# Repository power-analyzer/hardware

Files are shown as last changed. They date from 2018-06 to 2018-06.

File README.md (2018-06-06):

# Hardware

This is the hardware and microcontroller software component of Ryan Rabello and Nathan Zimmerly's senior project.

## Getting Started

The PCB folder is a KiCAD project. Once this is done, 

## Prerequisites

KiCAD and PlatformIO using either Visual Studio Code or Atom.

## Authors

Nathan Zimmerly and Ryan Rabello.

## Acknowledgments

OpenEnergyMonitor

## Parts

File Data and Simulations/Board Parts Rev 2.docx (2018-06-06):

Mux:

1. Link: http://www.ti.com/lit/ds/symlink/cd74hc4067.pdf
  a. Digi-Key Part #: 296-9226-1-ND (https://www.digikey.com/product-detail/en/texas-instruments/CD74HC4067SM96/296-9226-1-ND/376978)
  b. SOIC: https://www.digikey.com/product-detail/en/texas-instruments/CD74HC4067M96/296-29408-2-ND/1507236
  c. Voltage range: 2-6V (only has details for 2, 4, and 6 V).
  d. Multiplexer/Demultiplexer circuit: 16:1
  e. Price: $.38
2. A-D with Mux compare (price)
3. Check A-D for A-D built in voltage. 0-1V
4. USPS

Aux:

1. https://www.amazon.com/gp/huc/view.html?ie=UTF8&newItems=C10de19e9-9e1f-4409-ad12-5c9f6bc3ec91%2C1

Connector:

1. https://www.digikey.com/product-detail/en/phoenix-contact/1792876/277-2519-ND/3439931

Fuse:

1. https://www.digikey.com/product-detail/en/bel-fuse-inc/SMP-1.25/507-1039-2-ND/615115

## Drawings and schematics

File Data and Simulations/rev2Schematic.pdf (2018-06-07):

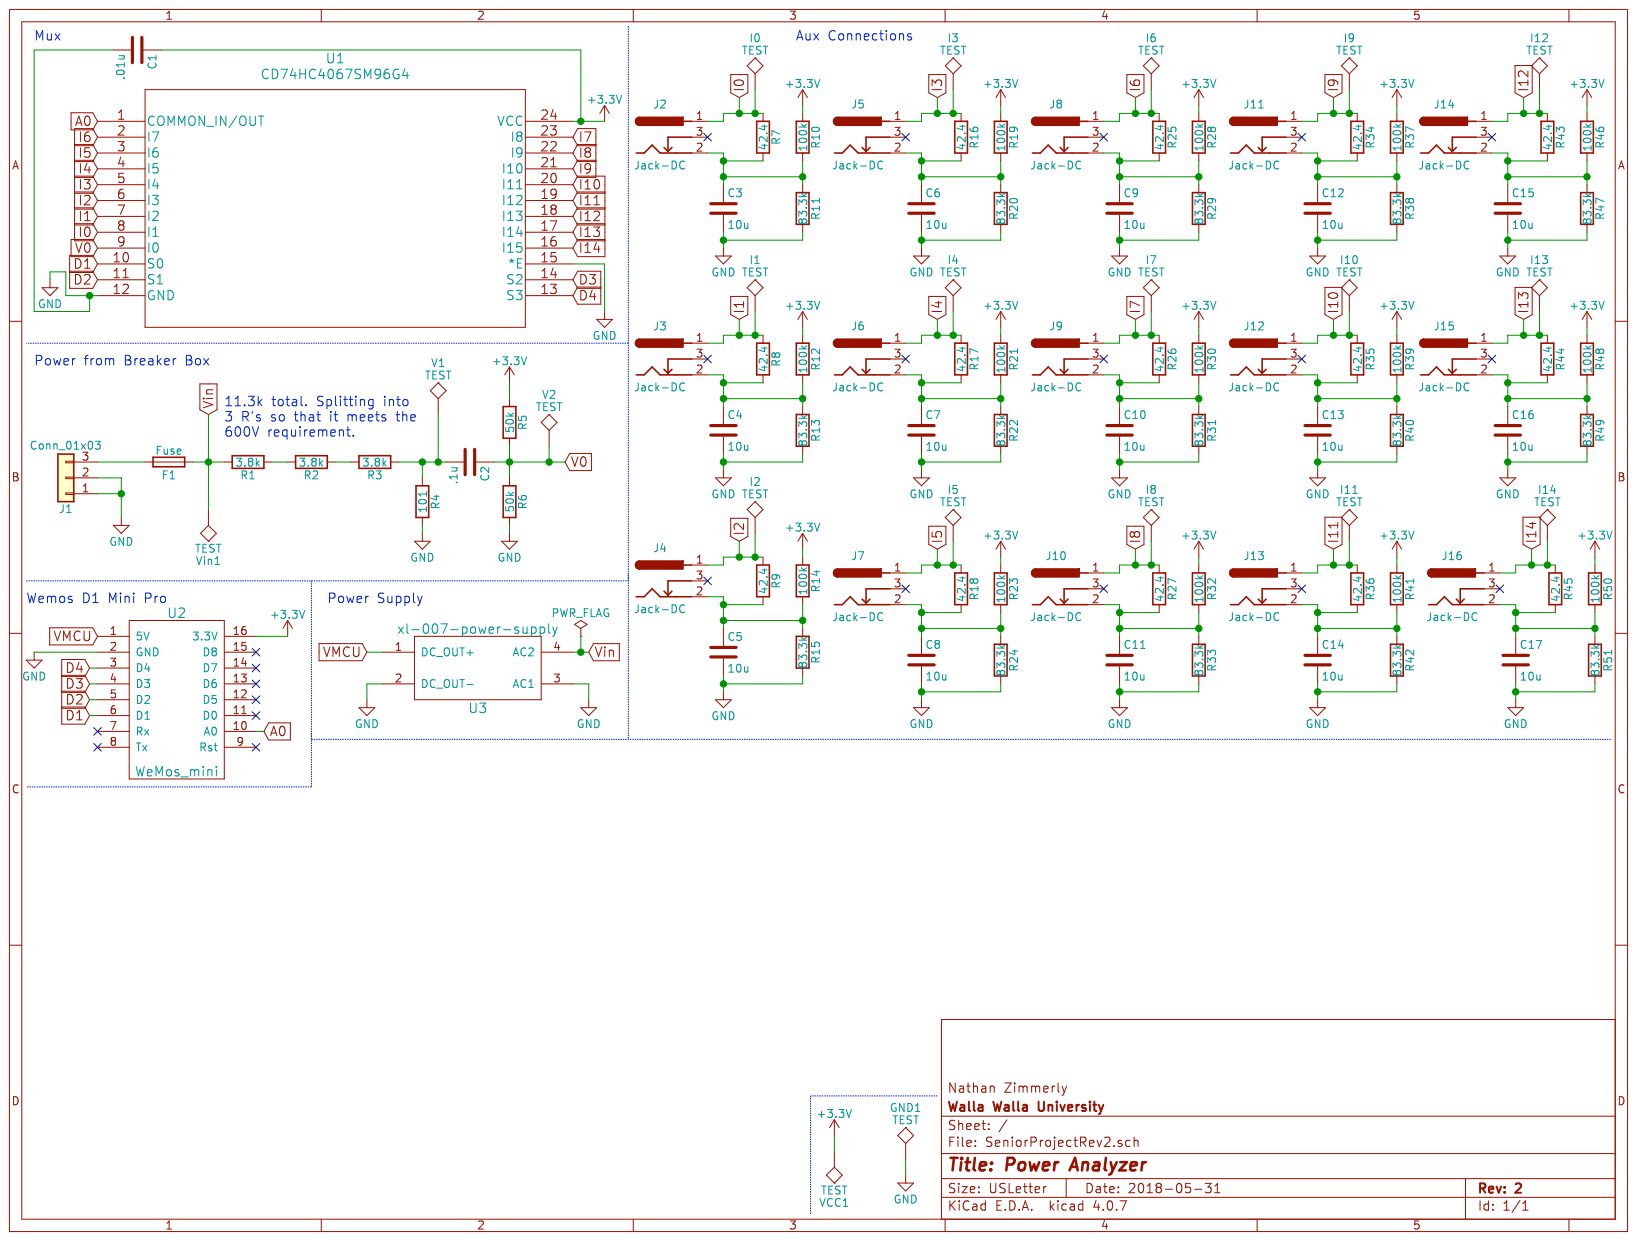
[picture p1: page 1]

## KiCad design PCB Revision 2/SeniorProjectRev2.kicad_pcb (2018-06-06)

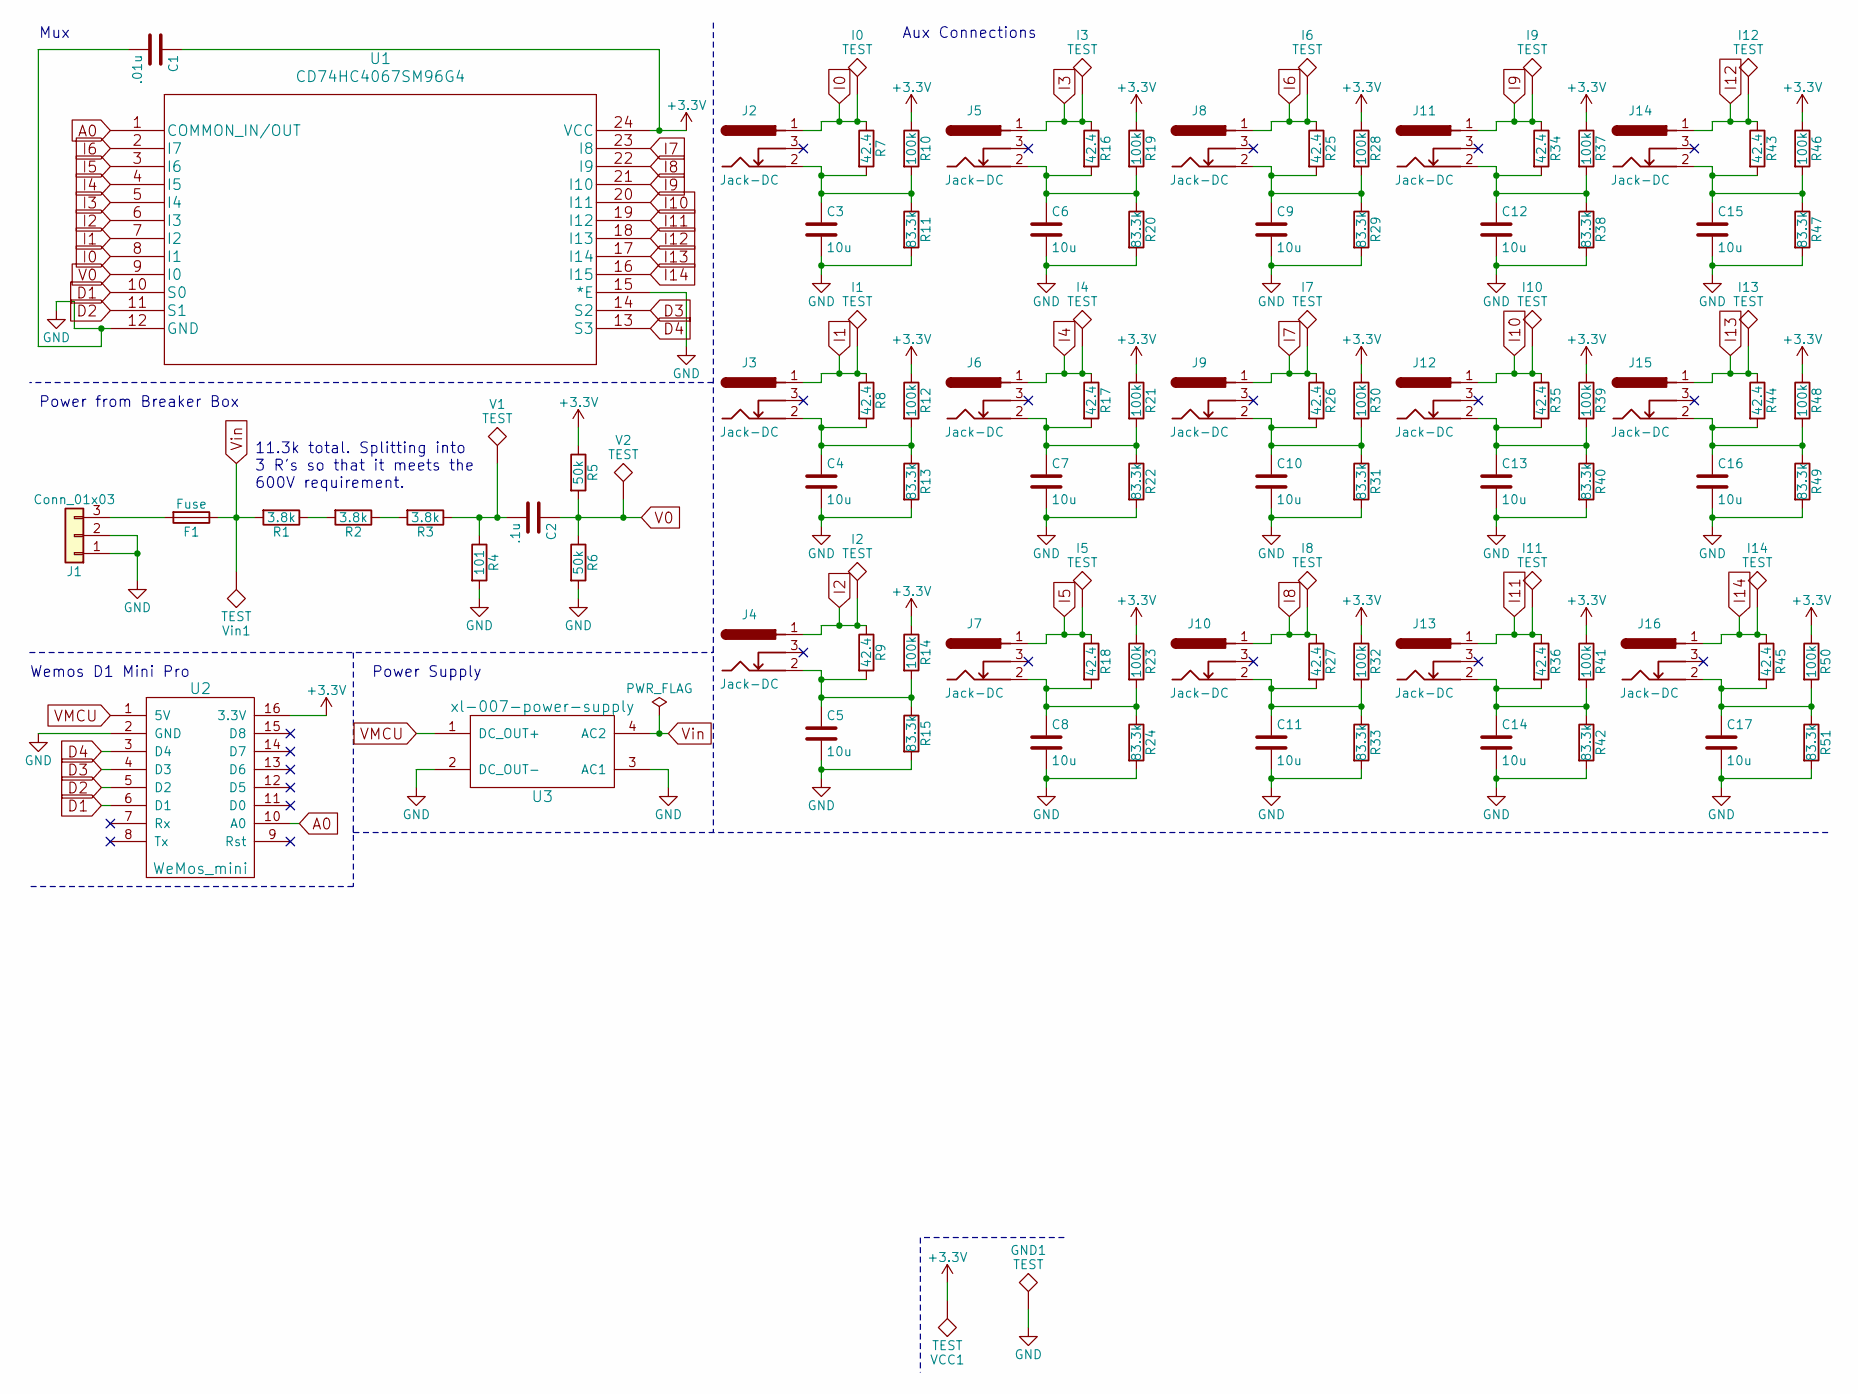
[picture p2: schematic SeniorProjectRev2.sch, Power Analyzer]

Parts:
C1: .01u; C_0805
C2: .1u; C_0805
C3, C4, C5, C6, C7, C8, C9, C10, C11, C12, C13, C14, C15, C16, C17: 10u; C_0805
F1: Fuse; fuse-rev2
GND1: TEST; Measurement_Point_Round-TH_Small
I0, I1, I2, I3, I4, I5, I6, I7, I8, I9, I10, I11, I12, I13, I14: TEST; Measurement_Point_Round-TH_Small
J1: Conn_01x03; CONN_TERM_BLOCK
J2, J3, J4, J5, J6, J7, J8, J9, J10, J11, J12, J13, J14, J15, J16: Jack-DC; AUDIO-JACK-TRRS-SMD-2
R1, R2, R3: 3.8k; R_0805
R4: 101; R_0805
R5, R6: 50k; R_0805
R7, R8, R9, R16, R17, R18, R25, R26, R27, R34, R35, R36, R43, R44, R45: 42.4; R_0805
R10, R12, R14, R19, R21, R23, R28, R30, R32, R37, R39, R41, R46, R48, R50: 100k; R_0805
R11, R13, R15, R20, R22, R24, R29, R31, R33, R38, R40, R42, R47, R49, R51: 83.3k; R_0805
U1: CD74HC4067SM96G4; SOIC-24W_7.5x15.4mm_Pitch1.27mm
U2: WeMos_mini; D1_mini_board
U3: xl-007-power-supply; DAOKI-Power-Supply
V1, V2: TEST; Measurement_Point_Round-TH_Small
VCC1: TEST; Measurement_Point_Round-TH_Small
Vin1: TEST; Measurement_Point_Round-TH_Small

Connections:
+3V3: C1.1, R5.1, R10.1, R12.1, R14.1, R19.1, R21.1, R23.1, R28.1, R30.1, R32.1, R37.1, R39.1, R41.1, R46.1, R48.1, R50.1, U1.24 (VCC), U2.16 (3.3V), VCC1.1
A0: U1.1 (COMMON_IN/OUT), U2.10 (A0)
D1: U1.10 (S0), U2.6 (D1)
D2: U1.11 (S1), U2.5 (D2)
D3: U1.14 (S2), U2.4 (D3)
D4: U1.13 (S3), U2.3 (D4)
GND: C1.2, C3.2, C4.2, C5.2, C6.2, C7.2, C8.2, C9.2, C10.2, C11.2, C12.2, C13.2, C14.2, C15.2, C16.2, C17.2, GND1.1, J1.1, J1.2, R4.2, R6.2, R11.2, R13.2, R15.2, R20.2, R22.2, R24.2, R29.2, R31.2, R33.2, R38.2, R40.2, R42.2, R47.2, R49.2, R51.2, U1.12 (GND), U1.15 (*E), U2.2 (GND), U3.2 (DC_OUT-), U3.3 (AC1)
I0: I0.1, J2.1, R7.1, U1.8 (I1)
I1: I1.1, J3.1, R8.1, U1.7 (I2)
I2: I2.1, J4.1, R9.1, U1.6 (I3)
I3: I3.1, J5.1, R16.1, U1.5 (I4)
I4: I4.1, J6.1, R17.1, U1.4 (I5)
I5: I5.1, J7.1, R18.1, U1.3 (I6)
I6: I6.1, J8.1, R25.1, U1.2 (I7)
I7: I7.1, J9.1, R26.1, U1.23 (I8)
I8: I8.1, J10.1, R27.1, U1.22 (I9)
I9: I9.1, J11.1, R34.1, U1.21 (I10)
I10: I10.1, J12.1, R35.1, U1.20 (I11)
I11: I11.1, J13.1, R36.1, U1.19 (I12)
I12: I12.1, J14.1, R43.1, U1.18 (I13)
I13: I13.1, J15.1, R44.1, U1.17 (I14)
I14: I14.1, J16.1, R45.1, U1.16 (I15)
unnamed: C2.2, R3.1, R4.1, V1.1
unnamed: C3.1, J2.2, R7.2, R10.2, R11.1
unnamed: C4.1, J3.2, R8.2, R12.2, R13.1
unnamed: C5.1, J4.2, R9.2, R14.2, R15.1
unnamed: C6.1, J5.2, R16.2, R19.2, R20.1
unnamed: C7.1, J6.2, R17.2, R21.2, R22.1
unnamed: C8.1, J7.2, R18.2, R23.2, R24.1
unnamed: C9.1, J8.2, R25.2, R28.2, R29.1
unnamed: C10.1, J9.2, R26.2, R30.2, R31.1
unnamed: C11.1, J10.2, R27.2, R32.2, R33.1
unnamed: C12.1, J11.2, R34.2, R37.2, R38.1
unnamed: C13.1, J12.2, R35.2, R39.2, R40.1
unnamed: C14.1, J13.2, R36.2, R41.2, R42.1
unnamed: C15.1, J14.2, R43.2, R46.2, R47.1
unnamed: C16.1, J15.2, R44.2, R48.2, R49.1
unnamed: C17.1, J16.2, R45.2, R50.2, R51.1
unnamed: F1.2, J1.3
unnamed: R1.1, R2.2
unnamed: R2.1, R3.2
V0: C2.1, R5.2, R6.1, U1.9 (I0), V2.1
VMCU: U2.1 (5V), U3.1 (DC_OUT+)
Vin: F1.1, R1.2, U3.4 (AC2), Vin1.1

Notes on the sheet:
Mux
Aux Connections
Power from Breaker Box
Power Supply
Wemos D1 Mini Pro
11.3k total. Splitting into 3 R's so that it meets the 600V requirement.

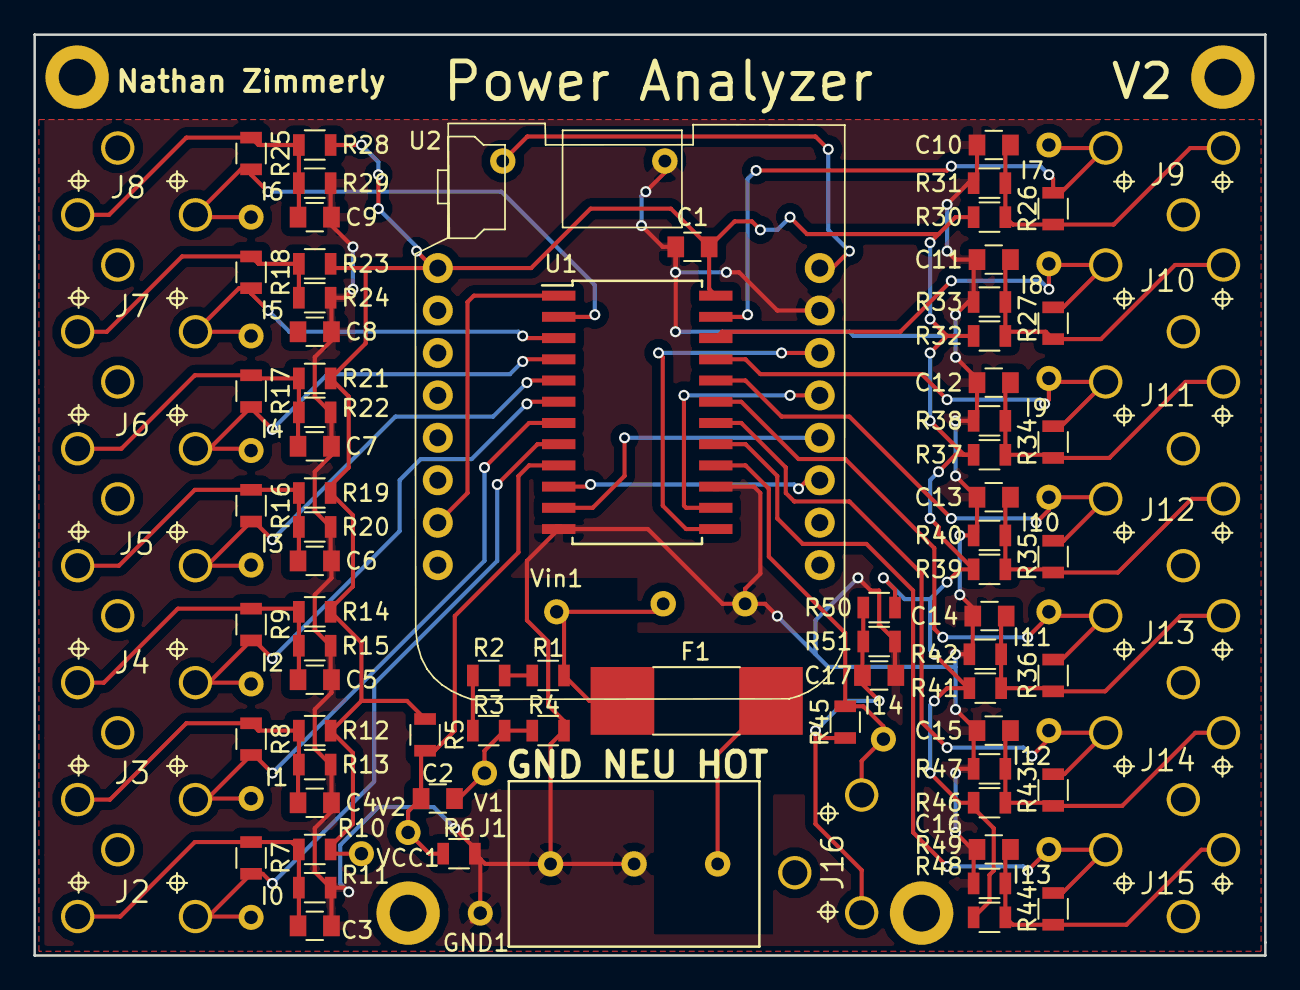
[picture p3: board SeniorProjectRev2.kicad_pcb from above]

Board: 2 copper layers, 73.7 x 55.1 mm, 108 parts (1 on the bottom side), 44 nets.

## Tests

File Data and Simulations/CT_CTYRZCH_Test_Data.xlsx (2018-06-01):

Data from current transformer: |  |  |  | Resistor (Ohms): | 99.26
Input V P-P (V) | Read Current (mA) | Calculated Current (mA) | Current Transformer (mVAC) |  | 99.26
1.19 | -0.08 | 11.9887165 | 5.02 |  | 99.26
3.07 | 0.193 | 30.92887367 | 8.1 |  | 99.26
5.07 | 0.535 | 51.07797703 | 12.33 |  | 99.26
7.56 | 0.974 | 76.16361072 | 17.77 |  | 99.26
10.28 | 1.52 | 103.5663913 | 23.74 |  | 99.26
12.58 | 2.038 | 126.7378602 | 29.25 |  | 99.26
15.5 | 2.749 | 156.1555511 | 35.88 |  | 99.26
17.65 | 3.352 | 177.8158372 | 41.13
19.89 | 3.957 | 200.382833 | 46.25
Calculated relationship
A = 10.29V_A+6.9635
R^2 = .99531
CT Model: | CTYRZCH SCT-013-000 Non-invasive AC Current Sensor Split Core Transformer 100A

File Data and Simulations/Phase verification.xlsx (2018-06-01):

835 | 118.1345407 | 835 | 118.1345407 | 118.4883422 | Max
821 | 113.1813201 | 821 | 113.1813201 | -117.851043 | Min
795 | 103.9824817 | 799 | 105.3976876
766 | 93.72223896 | 772 | 95.84504781
723 | 78.50877554 | 729 | 80.63158439
674 | 61.17250327 | 680 | 63.29531212
619 | 41.71342215 | 628 | 44.89763542
566 | 22.96194398 | 572 | 25.08475283
490 | -3.926968112 | 507 | 2.087656961
430 | -25.15505661 | 440 | -21.61704186
364 | -48.50595395 | 372 | -45.67554215
317 | -65.13462327 | 322 | -63.36561589
274 | -80.34808669 | 282 | -77.51767489
247 | -89.90072651 | 248 | -89.54692503
196 | -107.9446017 | 199 | -106.8831973
177 | -114.6668298 | 182 | -112.8978224
168 | -117.851043 | 168 | -117.851043
180 | -113.6054253 | 176 | -115.0206312
187 | -111.128815 | 185 | -111.836418
214 | -101.5761752 | 210 | -102.9913811
250 | -88.83932208 | 245 | -90.60832946
298 | -71.85685129 | 291 | -74.33346161
344 | -55.58198345 | 337 | -58.05859377
402 | -35.0614979 | 394 | -37.8919097
458 | -15.24861531 | 450 | -18.07902711
540 | 13.76310563 | 531 | 10.57889236
600 | 34.99119413 | 589 | 31.0993779
655 | 54.45027524 | 648 | 51.97366492
702 | 71.07894456 | 693 | 67.89473129
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

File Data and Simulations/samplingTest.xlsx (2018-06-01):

Voltage |  | Current (1)
288 | -75.39486604 | 494 | -2.511762213 | -2.157960738 | Max
351 | -53.10537312 | 489 | -4.280769587 | -48.15215247 | Min
409 | -32.58488758 | 485 | -5.695975487
463 | -13.47960793 | 476 | -8.880188761
546 | 15.88591448 | 466 | -12.41820351
608 | 37.82160592 | 456 | -15.95621826
662 | 56.92688557 | 446 | -19.49423301
708 | 73.20175341 | 434 | -23.73985071
749 | 87.70761388 | 423 | -27.63166693
785 | 100.444467 | 405 | -34.00009348
814 | 110.7047098 | 396 | -37.18430675
835 | 118.1345407 | 386 | -40.7223215
835 | 118.1345407 | 378 | -43.5527333
823 | 113.888923 | 372 | -45.67554215
802 | 106.4590921 | 367 | -47.44454952
774 | 96.55265075 | 365 | -48.15215247
732 | 81.69298881 | 366 | -47.798351
682 | 64.00291507 | 367 | -47.44454952
630 | 45.60523837 | 373 | -45.32174067
577 | 26.8537602 | 377 | -43.90653477
509 | 2.795259911 | 388 | -40.01471855
441 | -21.26324038 | 399 | -36.12290233
373 | -45.32174067 | 409 | -32.58488758
322 | -63.36561589 | 423 | -27.63166693
282 | -77.51767489 | 436 | -23.03224776
248 | -89.54692503 | 447 | -19.14043153
199 | -106.8831973 | 459 | -14.89481383
181 | -113.2516239 | 469 | -11.35679908
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

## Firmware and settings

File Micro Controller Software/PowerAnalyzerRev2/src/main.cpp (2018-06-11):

#include <Arduino.h>
#include <ESP8266WiFi.h>
#include "SimpleTimer.h"
#include <WiFiClientSecure.h>
#include <ArduinoJson.h>

/*
* Note:
* Only sending 14 circuits worth of data right now, to send all 15, send less data points per circuit
*/

const char* ssid = "iPhone Bro"; //Wi-Fi Bro WWU-Aruba-HWauth
const char* password = "fabphone"; //5C:CF:7F:13:AD:C4

const char* host = "35.165.91.189";
const int port = 8000;

String url = "/datapoints/"  + WiFi.macAddress() + "/batch/";

WiFiClient client;

int muxAddress = B0000;

int data[16][35] = {0};

String circuitNames[16] = {"V", "1", "2", "3", "4", "5", "6", "7", "8", "9", "10", "11", "12", "13", "14", "15"};

int currentCircuit = 0;

SimpleTimer timer;

int timerID = 1;

int totalCircuits = 15;


// Tests each circuit on startup to see if it is connected. 
/*void testCircuits() {
    //muxAddress = B0000;
    //muxAddressUpdate();
    for (int i = 1; i < 16; i++) {  // iterates through each circuit
    // starts at 1 because 0000 is voltage
        muxAddress = i;
        muxAddressUpdate();
        bool high = false;
        bool low = false;
        for (int n = 0 ; n < 4; n++) {  // tests for change from optoisolater
            // if circuit is 0 then add it to the class (because it inverts)
            if (analogRead(A0) >= 750) {
                //String name = String(n);
                high = true;

                n = 4;  // exit if circuit is connected
            } else if (analogRead(A0) >= 750) {
                low = true;
            }

            if (high = true && low == true) {
                circuitNamesStr.push_back(String(i));

                Circuit i;   // list of circuits that are active
                circuitNames.push_back(i);
            } else {
                delay(4.15);
            }
        }
        // for debugging
        //Serial.print("Circuits#");
        //Serial.print(circuitNamesStr[1]);
        //Serial.println();
    }
}*/

// updates the mux address pins based on the muxAddress var
void muxAddressUpdate() {
    //muxAddress = B0000;
    //Serial.print(muxAddress);
    //Serial.println();
    if ((muxAddress & B0001) == 1) {
        digitalWrite(D1, HIGH);
        //Serial.print("D1High");
        //Serial.println();
    } else {
        digitalWrite(D1, LOW);
        //Serial.print("D1Low");
        //Serial.println();
    }
    if ((muxAddress & B0010) == 2) {
        digitalWrite(D2, HIGH);
        //Serial.print("D2High");
        //Serial.println();
    } else {
        digitalWrite(D2, LOW);
        //Serial.print("D2Low");
        //Serial.println();
    }
    if ((muxAddress & B0100) == 4) {
        digitalWrite(D3, HIGH);
        //Serial.print("D3High");
        //Serial.println();
    } else {
        digitalWrite(D3, LOW);
        //Serial.print("D3Low");
        //Serial.println();
    }
    if ((muxAddress & B1000) == 8) {
        digitalWrite(D4, HIGH);
        //Serial.print("D4High");
        //Serial.println();
    } else {
        digitalWrite(D4, LOW);
        //Serial.print("D4Low");
        //Serial.println();
    }
    //Serial.println();
}

// sends post to server
String httpPost(String url, String data) {
  // Connnecting to wifi
  Serial.println();
  Serial.print("connecting to ");
  Serial.println(ssid);
  WiFi.mode(WIFI_STA);
  WiFi.begin(ssid, password);
  while (WiFi.status() != WL_CONNECTED) {
    delay(500);
    Serial.print(".");
  }
  Serial.println("");
  Serial.println("WiFi connected");
  Serial.println("IP address: ");
  Serial.println(WiFi.localIP());

  // Use WiFiClientSecure class to create TLS connection
  Serial.print("connecting to ");
  Serial.println(host);
  if (!client.connect(host, port)) {
    Serial.println("connection failed");
    return "wifi connection failed";
  }

  if (client.connect(host, port)) {
    client.println("Post " + url + " HTTP/1.1");
    client.println("Host: " + (String)host);
    client.println("User-Agent: ESP8266/1.0");
    client.println("Connection: close");
    client.println("Content-Type: application/x-www-form-urlencoded;");
    client.print("Content-Length: ");
    client.println(data.length());
    client.println();
    client.println(data);
    delay(100);  //10
    String response = client.readString();
    Serial.print(response);
    Serial.println("data sent");
    int bodypos =  response.indexOf("\r\n\r\n") + 4;
    return response.substring(bodypos);
  }
  else {
    return "ERROR";
  }
}

// serializes data into JSON format
String jsonSerialization() {
    DynamicJsonBuffer jsonBuffer;

    JsonObject& objectJson = jsonBuffer.createObject();

    for (int i = 0; i<totalCircuits; i++) { // should be i<16
        JsonArray& measurements = objectJson.createNestedArray(circuitNames[i]);
        int dataArray[35];
        for (int j = 0; j<35; j++) {
            dataArray[j] = data[i][j];
        }
        measurements.copyFrom(dataArray);
    }
    
    String objStr;
    objectJson.printTo(objStr);
    return objStr;
}

// Collects one period of data
void collectData() {
    memset(data[currentCircuit], 0, sizeof(data[currentCircuit]));
    int n = 0;
    unsigned long startTime = millis();
    int analogVal;
    while (millis() - startTime < 16.7) {       // should be 16.7, 19.65
        analogVal = analogRead(A0);
        if (n % 5 == 0) {   // causes 34 points to be collected in a 60hz period
            data[currentCircuit][n/5] = analogVal;
        }
        n = n + 1;
    }

    // switch to the next circuit address unless on the last circuit, then send data to server
    if (currentCircuit < totalCircuits - 1) {   // should be 15 to cover all circuits
        currentCircuit += 1;
    } else {
        // send out data to backend
        timer.disable(timerID); //disable timer while sending data
        String dataJSON = jsonSerialization();  // convert data into JSON
        //Serial.println(dataJSON);
        currentCircuit = 0; // reset circuit to 0
        String send = httpPost(url, dataJSON);
        if (send == "ERROR") {
            while(send == "ERROR") {
                Serial.println("Failed to Connect");
                //send = httpPost(url, dataJSON);
            }
        }
        timer.enable(timerID);
    }
    //switch to next circuit
    muxAddress = currentCircuit;
    muxAddressUpdate();
    //Serial.println(currentCircuit);
}

void setup() {
    Serial.begin(38400);

    Serial.println(WiFi.macAddress());

    // Mux Address Pins
    pinMode(D1, OUTPUT);
    pinMode(D2, OUTPUT);
    pinMode(D3, OUTPUT);
    pinMode(D4, OUTPUT);

    muxAddressUpdate();

    // timer to collect data on the next circuit every 100ms or 4 60hz periods
    timerID = timer.setInterval(100, collectData);
}



void loop() {
    timer.run();
}

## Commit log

2018-06-01 1st Rev of PCB
    [SeniorProjectRev1.kicad_pcb, SeniorProjectRev1.sch, _saved_SeniorProjectRev1.sch]
2018-06-01 Testing data and calculations for the hardware
    [CT_CTYRZCH_Test_Data.xlsx, Phase verification.xlsx, samplingTest.xlsx]
2018-06-01 Added gerber files for printing the PCB
    [SeniorProjectRev1-B.Cu.gbr, SeniorProjectRev1-B.Mask.gbr, SeniorProjectRev1-B.Paste.gbr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]
2018-06-01 Started 2nd Rev of PCB
    [SeniorProjectRev2.kicad_pcb, SeniorProjectRev2.sch]
2018-06-04 Updated current and voltage conversions and updated JSON library for micrcontroller
    [_saved_SeniorProjectRev1.sch]
2018-06-06 Finished Rev 2
    [SeniorProjectRev2-B.Cu.gbr, SeniorProjectRev2-B.Mask.gbr, SeniorProjectRev2-B.Paste.gbr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]
2018-06-06 Update README.md
    fixed lower case H.
2018-06-11 Updated calculations with error
    [SeniorProjectRev1.sch, SeniorProjectRev2.sch]
